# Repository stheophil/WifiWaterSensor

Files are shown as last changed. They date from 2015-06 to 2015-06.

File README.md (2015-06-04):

# What is this?

This repository contains the code and 3D source files to create a simple water level sensor that can be attached to a bucket of water, e.g. on your balcony, from which you're watering your plants using [self-watering probes](http://www.amazon.com/Self-Watering-Probes-Package-of-5/dp/B0002VAHXC). 



# Parts

You will need a few things to assemble the water level sensor:  

- [A simple float switch](http://www.ebay.co.uk/itm/New-Liquid-Water-Level-Sensor-Horizontal-Float-Switch-UK-seller/281535436270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)  
- [A charging circuit for 18650 lithium batteries](http://www.aliexpress.com/item/Micro-USB-5V-1A-18650-Lithium-Battery-Charging-Board-Charger-Module-With-Protection/32265626505.html)  
- [A holder for an 18650 lithium battery](http://www.aliexpress.com/item/FREE-SHIPPING-5-Pcs-New-18650-Battery-3-7V-Clip-Holder-Box-Case-Black-With/32331098387.html)  
- 3mm screws. You have to experiment which ones work best. The holes have a diameter of about 2mm.  

These parts cost about $1 each.   

- A 18650 lithium ion battery. Available e.g. at Amazon. Don't take the cheapest ones.   
- A programmable microprocessor with Wifi, e.g. the [Adafruit ESP8266 Huzzah](http://www.adafruit.com/product/2471) or a generic NodeMCU board. Maximum size about 25mm x 50mm.   

These parts cost about 10$ each. 

- You'll probably need a soldering iron and some cables.   

And last but not least a 3D printer to print the enclosure and inner structure that holds all these things together. 

# Assembly 



- Download the STL files from [thingiverse.com](http://www.thingiverse.com/thing:862976) and print them. 
- Connect battery holder and charging circuit e.g. by soldering them together. 
- Connect charging circuit and ESP8266 board with (female) jumper cables. 
	_(That's important! Don't solder them together. I had problems flashing the chip when it ran directly off the battery. Probably because the battery provides more than 3.3V which may have confused the USB-serial converter.)_

- See the documentation of the ESP8266 board that you use. You probably need to connect GPIO16 to the RESET pin to enable deep sleep mode. Other boards than the Adafruit board [may require more connections to work at all](http://blog.squix.ch/2015/02/esp8266-esp-201-breakout-board-review.html).

- Stick float switch cables through the hole in the outer sensor enclosure. Connect them to the Wifi board. One cable goes to GND, the other to GPIO13. Again, it may be a good idea to solder the switch cables to female breadboard connectors. 

- Glue everything in place. I used strong double-sided foam tape. 

**Attention: Be careful with Lithium batteries. I have not tested the enclosure for safety. It is certainly not entirely weather-proof. Safety will depend on your choice of batteries, battery protection circuits, charging circuits etc. I do not take any responsibility if your batteries suddenly catch fire.**

# Flash 

- Change Wifi configuration in `sketch/sketch.ino` and register at thingspeak.com. Also insert your thingspeak.com API key. 
- Again, see the docs for your ESP8266 board on how to flash it. 

# Finish

- Insert a battery, put everything inside the enclosure and close it with two screws.

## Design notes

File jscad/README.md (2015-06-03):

# How to render JSCAD files

Go to [http://openjscad.org]. 

1. To render the T-shaped interior that holds the battery, charger, and the Wifi chip, drag `common.jscad` and `inner/main.jscad` to the "Drop your jscad files ... here" area on the website.

2. To render the outer shell drag `common.jscad` and `outer/main.jscad` to the file area.

3. To render the hook that should be glued to the outer shell, drag `hook.jscad` to the file area.

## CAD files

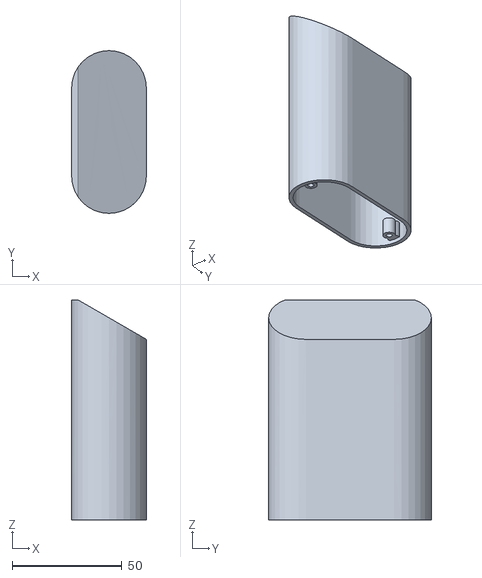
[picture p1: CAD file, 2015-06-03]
jscad/outer.stl
34.0 x 74.0 x 100.0

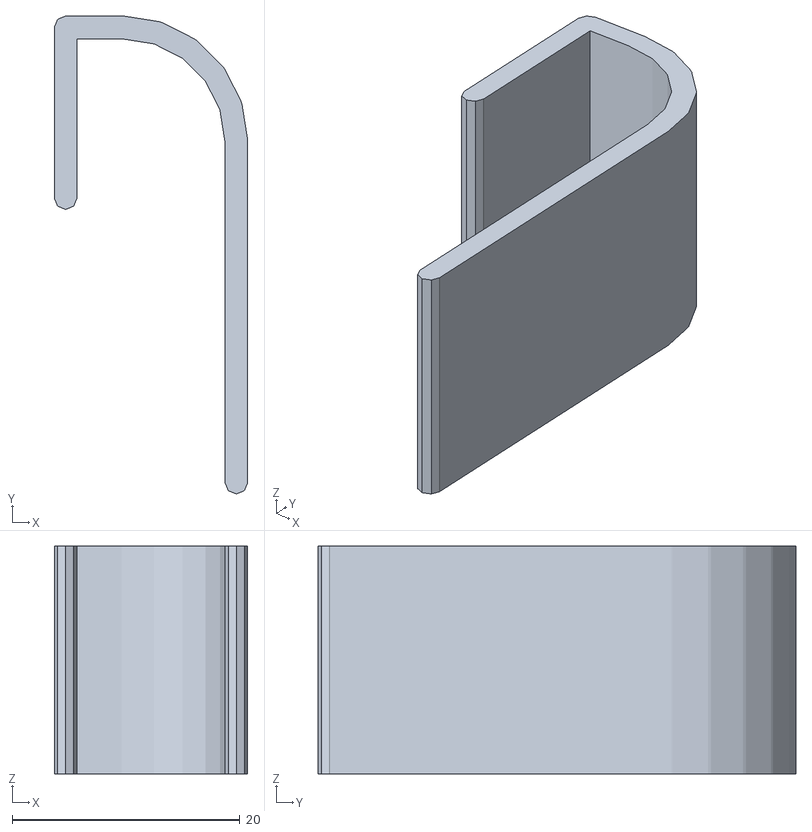
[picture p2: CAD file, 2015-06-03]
jscad/holder.stl
17.0 x 42.0 x 20.0

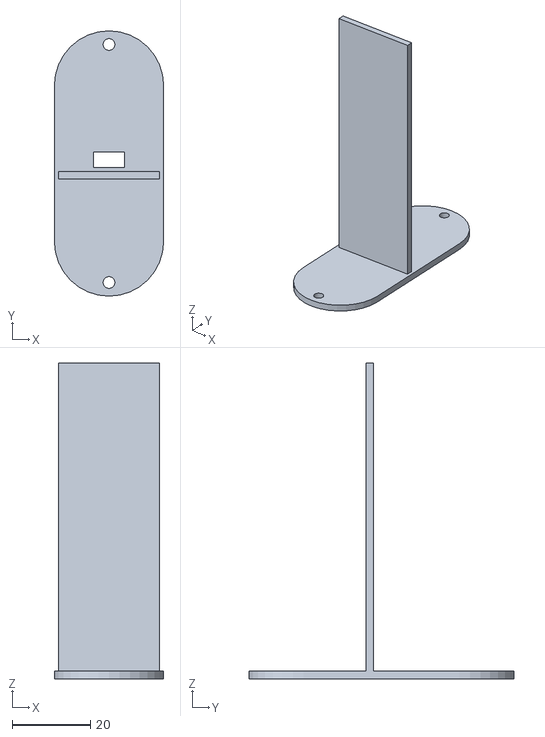
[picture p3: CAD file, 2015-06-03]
jscad/inner.stl
28.0 x 68.0 x 81.0

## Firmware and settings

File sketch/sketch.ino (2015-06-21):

#include "Arduino.h"
#include "Esp.h"
#include "ESP8266WiFi.h"

// To configure sensor, change values in ap_config.h
#include "ap_config.h" 

enum EState {
  estateCONNECTED,
  estateDONE,
  estateSLEEP
} m_estate = estateDONE;

int const c_nSENSOR_PIN = 13;

char const* c_szHOST = "api.thingspeak.com";
char const* c_szPATH = "/update?api_key=";
char const* c_szFIELD = "&field";

uint32_t const c_nSLEEP = (uint32_t)-1; 
unsigned int const c_nSecondsWaitingWifi = 10; // How long to wait for Wifi connection
unsigned int const c_cRetrySend = 5; // How often to retry sending measurements

void setup() {
  Serial.begin(115200);
  pinMode(c_nSENSOR_PIN, INPUT_PULLUP);
  
  Serial.println();
  Serial.println();
  Serial.print("WifiPlantSensor ");
  Serial.println(m_data.m_nSensorID);

  try_connect();
}

void try_connect() {
  // TODO:
  // When we load from EEPROM initially, make sure 
  // SSID and password are 0-terminated
  // m_data.m_aszSSID[sizeof(m_data.m_aszSSID) - 1] = '\0';
  // m_data.m_aszPassword[sizeof(m_data.m_aszPassword) - 1] = '\0';

  Serial.print("Connecting to: ");
  Serial.println(m_data.m_aszSSID);
  
  WiFi.begin(m_data.m_aszSSID, m_data.m_aszPassword);

  for(int i = 0; i < c_nSecondsWaitingWifi && WiFi.status() != WL_CONNECTED; ++i) {
    delay(1000);
    Serial.print(".");
  }
  Serial.println("");

  if(WiFi.status() == WL_CONNECTED) {
    Serial.println("WiFi connected");
    Serial.println("IP address: ");
    Serial.println(WiFi.localIP());

    m_estate = estateCONNECTED;
  } else {
    Serial.println("Could not connect to Wifi");
    m_estate = estateDONE;
  }
}

bool get_request(char const* szHost, int nPort, char const* szUri) {
  Serial.print("Connecting to ");
  Serial.println(szHost);

  WiFiClient client;
  if(!client.connect(szHost, nPort)) {
    Serial.println("Connection failed");
    return false;
  }

  // We now create a URI for the request
  Serial.print("Requesting URL: ");
  Serial.println(szUri);

  // This will send the request to the server
  client.print(String("GET ") + szUri + " HTTP/1.1\r\n" +
               "Host: " + szHost + "\r\n" +
               "Connection: close\r\n\r\n");

  delay(100);

  // Read all the lines of the reply from server and print them to Serial
  String line = client.readStringUntil('\r');
  Serial.print(line);  

  Serial.println();
  Serial.println("Closing connection");
  return nullptr != strstr(line.c_str(), "200 OK");
}

String strUri;
extern "C" uint16_t readvdd33(void);

void loop() {
  switch (m_estate) {
    case estateCONNECTED:
      strUri = c_szPATH;
      strUri += m_data.m_aszApiKey;
      strUri += c_szFIELD;
      strUri += m_data.m_nSensorID * 2 - 1; // sensor id and field are 1-based
      strUri += "=";
      strUri += digitalRead(c_nSENSOR_PIN) ? '1' : '0';

      strUri += c_szFIELD;
      strUri += m_data.m_nSensorID * 2; // sensor id and field are 1-based
      strUri += "=";
      strUri += readvdd33();

      static unsigned int nSend = 0;
      if(get_request(c_szHOST, 80, strUri.c_str()) 
      || ++nSend==c_cRetrySend) {
        m_estate = estateDONE;
      } else {
        Serial.print("GET request ");
        Serial.print(nSend);
        Serial.println(" failed");
        delay(1000);
      }
      break;

    case estateDONE:
      Serial.println("Disconnecting");
      WiFi.disconnect();
      delay(500);

      m_estate = estateSLEEP;
      ESP.deepSleep(c_nSLEEP);
      break;

    case estateSLEEP:
      delay(100);
      break;
  }
}
